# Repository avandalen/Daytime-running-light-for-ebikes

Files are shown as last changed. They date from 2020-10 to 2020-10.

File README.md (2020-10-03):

See the whole article here: https://www.avdweb.nl/solar-bike/electronics/daytime-running-light

Why daytime running lights?

Cars are an increasing danger to cyclists. This is because the motorist is distracted by operating the abundant of electronics in the car, such as navigation, smartphone, etc. A car sometimes looks like an airplane cockpit, with the difference that in an airplane there is a co-pilot to operate everything.

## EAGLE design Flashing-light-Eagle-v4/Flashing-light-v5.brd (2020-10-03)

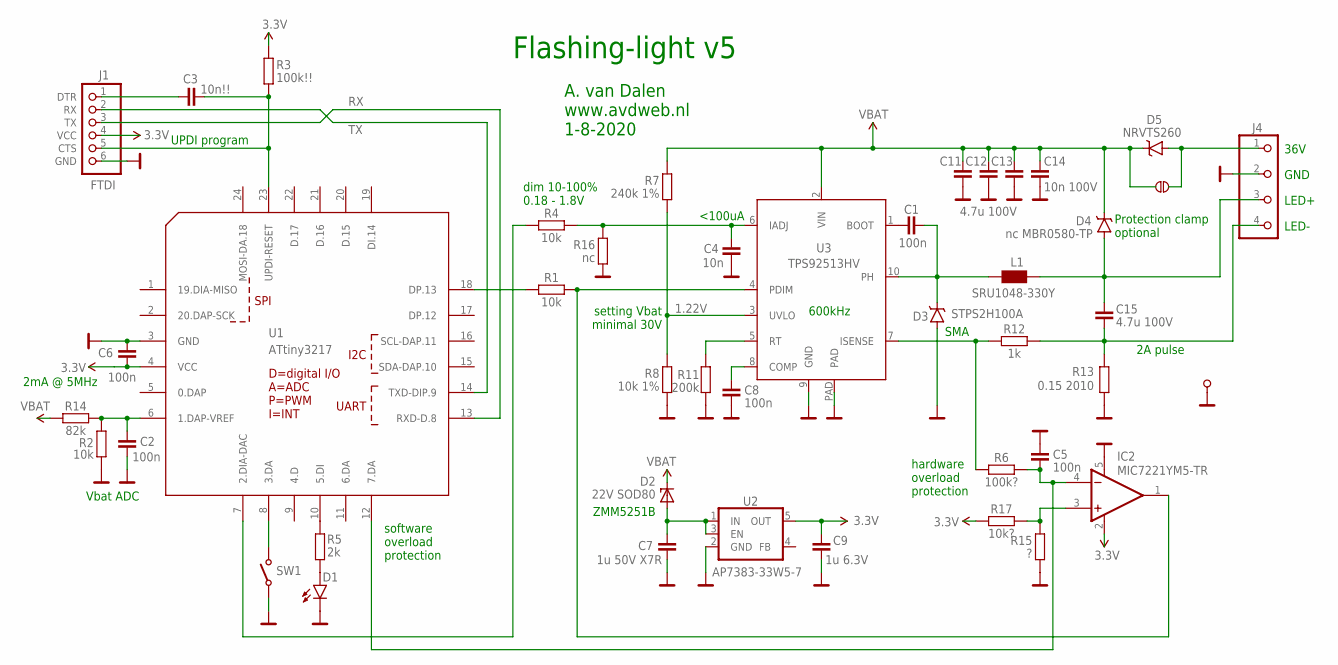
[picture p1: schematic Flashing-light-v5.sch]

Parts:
C1: 100n; 0805-CAP
C2, C5, C6, C8: 100n; 0603-SMALL
C3: 10n!!; 0603-SMALL
C4: 10n; 0603-SMALL
C7: 1u 50V X7R; 0805-CAP
C9: 1u 6.3V; 0603-SMALL
C11, C12, C13, C15: 4.7u 100V; 1210
C14: 10n 100V; 0603-SMALL
D1: green; LED-0603
D2: 22V SOD80; SOD80C
D3: STPS2H100A; SMA
D4: nc MBR0580-TP; SOD-123
D5: NRVTS260; SOD-123
IC2: MIC7221YM5-TR; SOT23-5L
J1: FTDI; ZIGZAG-FTDI
J3: TP; PIN-1.2MM
J4: CON-4PHEADER; 1X04
JP1: nc; JUMPER_NO
L1: SRU1048-330Y; IND-10X10
R1, R2, R4: 10k; 0603-SMALL
R3: 100k!!; 0603-SMALL
R5: 2k; 0603-SMALL
R6: 100k?; 0603-SMALL
R7: 240k 1%; 0603-SMALL
R8: 10k 1%; 0603-SMALL
R11: 200k; 0603-SMALL
R12: 1k; 0603-SMALL
R13: 0.15 2010; R2010
R14: 82k; 0603-SMALL
R15: ?; 0603-SMALL
R16: nc; 0603-SMALL
R17: 10k?; 0603-SMALL
SW1: TACTILE; TACTILE-PTH
U1: ATtiny3217; QFN-24
U2: AP7383-33W5-7; SOT23-5
U3: TPS92513HV; HVSS0P-10

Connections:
0.5V: R11.2, U3.5 (RT)
1.22V: R7.1, R8.2, U3.3 (UVLO)
3.3V: C6.2, C9.1, IC2.2 (V+), J1.4 (VCC), R3.2, R17.1, U1.4 (VCC), U2.5 (OUT)
ADC: C2.1, R2.2, R14.1, U1.6 (1.DAP-VREF)
GND: C2.2, C4.2, C5.1, C6.1, C7.2, C8.2, C9.2, C11.2, C12.2, C13.2, C14.2, D1.C, D3.A, IC2.5 (V-), J1.6 (GND), J3.1, J4.2, R2.1, R8.1, R11.1, R13.1, R15.1, R16.1, SW1.3, SW1.4, U1.3 (GND), U2.2 (GND), U3.9 (GND), U3.PAD
unnamed: R6.1, R12.1, U3.7 (ISENSE)
unnamed: C15.2, J4.4, R12.2, R13.2
unnamed: D5.A, J4.1, JP1.2, JP1.2B (2)
unnamed: C1.1, U3.1 (BOOT)
unnamed: R4.1, U1.7 (2.DIA-DAC)
unnamed: C15.1, D4.A, J4.3, L1.2
unnamed: C8.1, U3.8 (COMP)
unnamed: C7.1, D2.A, U2.1 (IN), U2.3 (EN)
unnamed: SW1.1 (O), SW1.2 (O), U1.8 (3.DA)
unnamed: R5.2, U1.10 (5.DI)
unnamed: C5.2, IC2.4 (-IN), R6.2, U1.12 (7.DA)
unnamed: D1.A, R5.1
unnamed: C4.1, R4.2, R16.2, U3.6 (IADJ)
unnamed: IC2.1 (OUT), R1.2, U3.4 (PDIM)
unnamed: IC2.3 (+IN), R15.2, R17.2
unnamed: R1.1, U1.18 (DP.13)
unnamed: C3.1, J1.1 (DTR)
PH: C1.2, D3.C, L1.1, U3.10 (PH)
RESET: C3.2, J1.5 (CTS), R3.1, U1.23 (UPDI-RESET)
RX: J1.3 (TX), U1.13 (RXD-D.8)
TX: J1.2 (RX), U1.14 (TXD-DIP.9)
VBAT: C11.1, C12.1, C13.1, C14.1, D2.C, D4.C, D5.C, JP1.1, JP1.1A (1), R7.2, R14.2, U3.2 (VIN)

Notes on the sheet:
A. van Dalen www.avdweb.nl 1-8-2020
Flashing-light v5
UPDI program
ZMM5251B
LED-
LED+
36V
GND
SMA
Protection clamp optional
setting Vbat minimal 30V
2A pulse
600kHz
Vbat ADC
dim 10-100% 0.18 - 1.8V
<100uA
hardware overload protection
2mA @ 5MHz
software overload protection

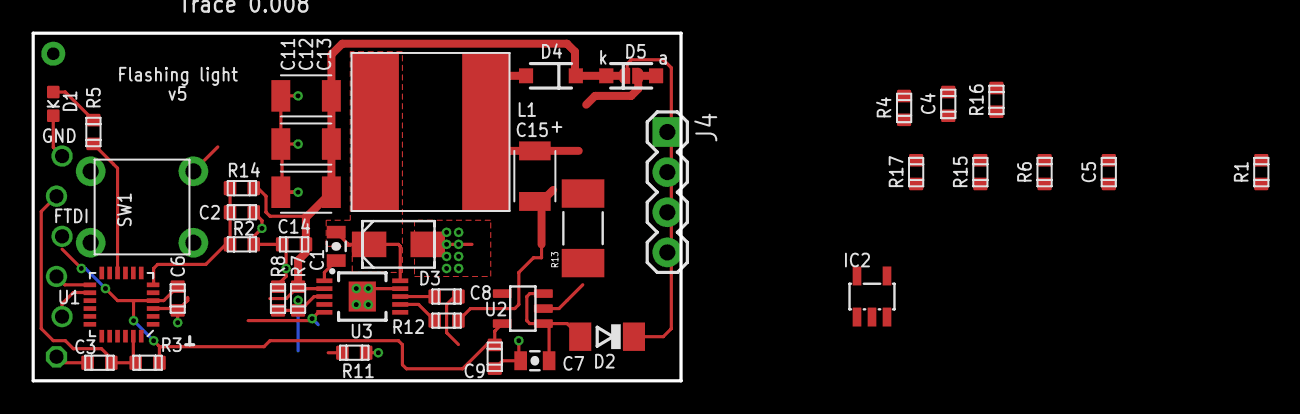
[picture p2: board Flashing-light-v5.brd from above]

Board: 2 copper layers, 41.0 x 22.0 mm, 44 parts (0 on the bottom side), 27 nets.

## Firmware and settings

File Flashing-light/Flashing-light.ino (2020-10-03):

/* 
Arduino IDE settings:
File > Preferences > Additional board manager URLs = http://drazzy.com/package_drazzy.com_index.json
Board = ATtiny3217 (Optiboot)
First set Tools > 
Clock Speed = 5MHz
DAC Voltage Reference = 0.55V

Selftest error shown with flashing LED:
LED 0 (red) Clock speed is not 5MHz, set Tools > Clock Speed 5MHz
*/

#include "Definitions.h"
#include <avdweb_VirtualDelay.h>
#include <avdweb_Switch.h> // https://github.com/avandalen/avdweb_Switch
#include <Streaming.h>
#include <RunningAverage.h> // https://github.com/RobTillaart/Arduino/tree/master/libraries/RunningAverage

VirtualDelay delayOn_ms, delayOff_ms; 
RunningAverage batteryVoltage(100); 
Switch button(buttonPin);

int lightOn_ms;
bool lightOn = 1;

void setup() 
{ Serial.begin(115200);
  pinMode(lightPin, OUTPUT);
  pinMode(ledPin, OUTPUT);
 
  while(checkClockSpeed()) blinkError(ledPin);
  randomSeed(adcV()); 
  delayOff_ms.start(0); // breaks the VirtualDelay deadlock

  printPower();
  //DACReference(0.55);
  //analogWrite(2, 100);
}

void loop()
{ batteryVoltage.addValue(adcV()); 
  button.poll();
  if(delayOn_ms.elapsed()) 
  { digitalWrite(lightPin, 0);
    digitalWrite(ledPin, 0);
    if(batteryVoltage.getFastAverage() > battFull) lightOn_ms = lightOn_max; // delayOff_ms.start(battFull_ms); 
    else lightOn_ms = lightOn_min;
    int ms = random(randomMin_ms, randomMax_ms);
    delayOff_ms.start(ms);
    Serial << "\n" << batteryVoltage.getFastAverage() << " V " << ms << " ms " << lightOn_ms << " ms " << lightOn;
  }
  if(delayOff_ms.elapsed()) 
  { digitalWrite(lightPin, (int)lightOn);
    digitalWrite(ledPin, (int)lightOn);
    delayOn_ms.start(lightOn_ms);
  }
  if(button.pushed()) lightOn = !lightOn; 
}

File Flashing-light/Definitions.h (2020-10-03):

// Pins
const byte ledPin = 5;
const byte buttonPin = 2;
const byte lightPin = 19;
const byte adcPin = 1;

const int lightOn_min = 10;
const int lightOn_max = 20;
const int randomMin_ms = 200; // off time is random
const int randomMax_ms = 700; // ,,

const float R14 = 82000;
const float R2 = 10000;
const float battFull = 41;
const float adcError = 1.039;
